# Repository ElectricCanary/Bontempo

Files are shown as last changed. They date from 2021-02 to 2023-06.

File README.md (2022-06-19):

The Bontempo is a Tap Tempo & Modulation solution for PT2399 delay

Website : https://electric-canary.com/bontempo

Support : support@electric-canary.com

Perf & PCB by storyboardist : http://effectslayouts.blogspot.com/2021/02/bomtempo.html

The Code, Schematic and PCB manufacturing files are shared under a BY-NC-SA Creative Commons License

Go here for complete license : https://creativecommons.org/licenses/by-nc-sa/4.0/legalcode

Please reach out for licencing if you want to use the code in a commercial product. 

Populated Board_Cropped - Copie

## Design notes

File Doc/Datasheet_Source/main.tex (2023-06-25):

\documentclass[a4paper, 10pt]{article}

\usepackage[default]{comfortaa}
\usepackage[utf8]{inputenc}
\usepackage[english]{babel}
\usepackage{graphicx}
\usepackage{geometry}
\usepackage{titlesec}
\usepackage{multicol}
\usepackage{lastpage}
\usepackage{fancyhdr}
\usepackage{array}
\usepackage{multirow, hhline}
\usepackage[table]{xcolor}
\usepackage[hidelinks]{hyperref}
\usepackage{textcomp}

\setlength{\columnseprule}{1pt}
\setlength{\columnsep}{1cm}

\definecolor{lightgray}{gray}{0.85}

\setlength{\arrayrulewidth}{0.35mm}
\setlength{\tabcolsep}{10pt}
\renewcommand{\arraystretch}{1.7}

\fancypagestyle{plain}{%
\fancyhf{} % clear all header and footer fields
\cfoot{\thepage /\pageref{LastPage}}
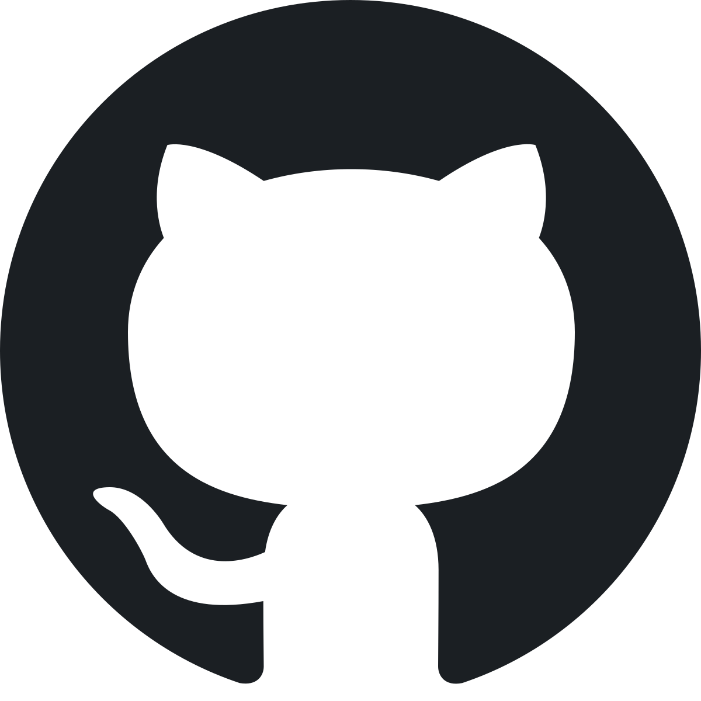
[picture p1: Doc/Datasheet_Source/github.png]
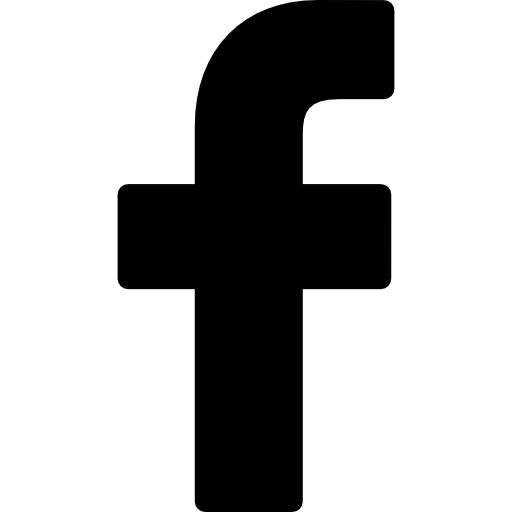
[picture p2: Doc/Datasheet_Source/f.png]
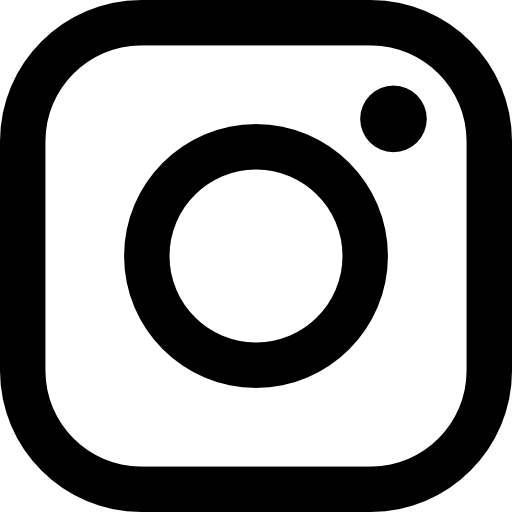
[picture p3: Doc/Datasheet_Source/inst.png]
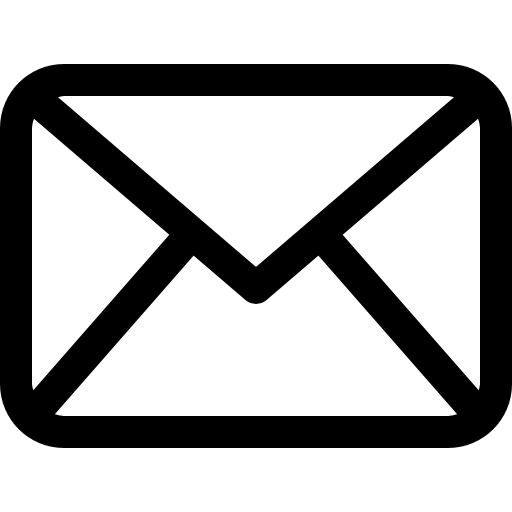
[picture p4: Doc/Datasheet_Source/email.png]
\rfoot{\href{https://github.com/ElectricCanary/Bontempo}{}\hspace{8pt}\href{https://www.facebook.com/ElectricCanary}{}\hspace{8pt}\href{https://www.instagram.com/electricanary/}{}\hspace{12pt}\href{mailto:support@electric-canary.com}{}}
\lfoot{\textcolor{black!70}{{\footnotesize\textcopyright Electric Canary - June 2020}}}
\renewcommand{\headrulewidth}{0pt}
\renewcommand{\footrulewidth}{0pt}}

\pagestyle{fancy}
\renewcommand{\headrulewidth}{0pt}
\cfoot{}
\cfoot{\thepage /\pageref{LastPage}}
\rfoot{\href{https://github.com/ElectricCanary/Bontempo}{}\hspace{8pt}\href{https://www.facebook.com/ElectricCanary}{}\hspace{8pt}\href{https://www.instagram.com/electricanary/}{}\hspace{12pt}\href{mailto:support@electric-canary.com}{}}
\lfoot{\textcolor{black!70}{{\footnotesize\textcopyright Electric Canary - June 2020}}}
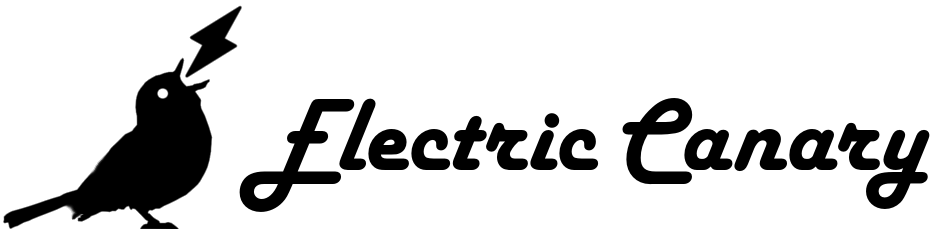
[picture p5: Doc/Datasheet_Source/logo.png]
\rhead{\href{https://electric-canary.com/bontempo}{}}
\lhead{\textbf{{\small\emph{\textcolor{black!70}{Bontempo-Datasheet}}}}}

\titleformat*{\section}{\huge\bfseries}
\titleformat*{\subsection}{\LARGE\bfseries}
\titleformat*{\subsubsection}{\Large\bfseries}

\geometry{hmargin=2.5cm,vmargin=2.5cm}
\headheight=35pt

\begin{document}\thispagestyle{plain}
\begin{center}
\begin{Huge}
\vspace*{0.5cm}
\textbf{Bontempo - Datasheet}
\rule {0.95\textwidth}{2pt}\\
\end{Huge}
\vspace{1cm}
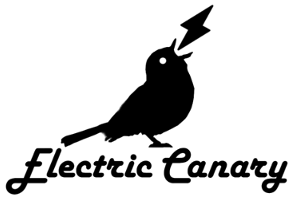
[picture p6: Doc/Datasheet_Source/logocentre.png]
\\
\end{center}
\vspace{1cm}
\begin{multicols}{2}
\section{Introduction}
\bigbreak
Bontempo is a precise Tap Tempo and Modulation integrated solution for PT2399 delay. It is suitable for new designs or modifying well-known PT2399 delays.\\

You can now unlock the full potential of your delay effect units. Explore new sonic territories with fully controllable modulation parameters and 6 modulation waveforms. \\

Get the exact tempo you need with the 6 Tempo divisions and calibration mode.\\

Keep your settings safe with the two user presets and the save tempo option. 
\vfill\null
\columnbreak

\section{Features}
\bigbreak
\begin{itemize}
\item \hyperref[sec:calib]{Calibrated }\hyperref[sec:digpot]{8-bit Digital Potentiometer Tap Tempo}
\item \hyperref[subsec:delaytime]{~40ms to ~1300ms Delay Time}
\item \hyperref[subsec:tempodiv]{6 Selectable Tempo Divisions} \\  ,  ,  ,  ,  , 
\item \hyperref[subsec:moddepthspeed]{±30ms Max. Modulation Depth}
\item \hyperref[subsec:moddepthspeed]{~0.1Hz to ~10Hz Modulation Speed}
\item \hyperref[subsec:waveformsel]{6 Selectable Modulation Waveforms}\\  ,  ,  ,  ,  , 
\item \hyperref[sec:userpresets]{2 User Presets}
\item \hyperref[sec:cleanmode]{Clean Mode (limits delay to 600ms for cleaner sound)}
\item \hyperref[sec:doubletime]{Double Time Mode}
\item \hyperref[sec:temposave]{Tempo EEPROM Save}
\item \hyperref[sec:dualpt]{Dual PT2399 Capability}
\item \hyperref[sec:pinconfig]{Compact DIP-14 Package}
\item \hyperref[sec:typappsche]{Minimal amount of External Parts}
\end{itemize}
\end{multicols}

\newpage
\headheight=35pt
\tableofcontents
\newpage

\section{Pin Configuration}
\label{sec:pinconfig}
\vfill
\begin{center}
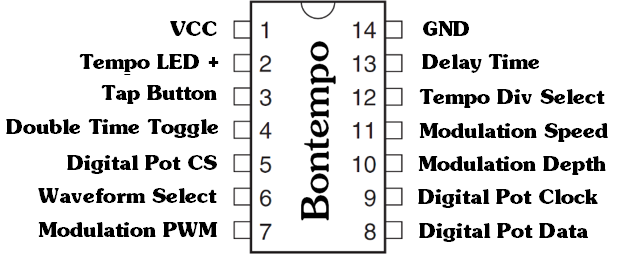
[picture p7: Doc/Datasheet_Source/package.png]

\vfill
\begin{table}[h!]
\begin{tabular}{|m{0.5cm}|m{4.5cm}|m{0.7cm}|m{7.5cm}|}
\hline
\rowcolor{lightgray} \centering {\Large\textbf{N°}} & \centering {\Large\textbf{Name}} & \centering {\Large\textbf{I/O}} & {\Large\textbf{Description}}\\
\hline
\centering 1 & \centering VCC & \centering I & Supply voltage.\\
\hline
\centering 2 & \centering Tempo LED + & \centering O & LED indicator output.\\
\hline
\centering 3 & \centering Tap Button & \centering I & Set tempo when connected  to ground.\\
\hline
\centering 4 & \centering Double Time Toggle & \centering I & Multiply tempo per 2 when connected to ground.\\
\hline
\centering 5 & \centering Digital Pot Chip Select & \centering O & Part of the SPI interface for the MCP41100 digital potentiometer.\\
\hline
\centering 6 & \centering Waveform Select & \centering I & The voltage determines the modulation waveform.\\
\hline
\centering 7 & \centering Modulation PWM & \centering O & PWM output for the MOSFET.\\
\hline
\centering 8 & \centering Digital Pot Data & \centering O & Part of the SPI interface for the MCP41100 digital potentiometer.\\
\hline
\centering 9 & \centering Digital Pot Clock & \centering O & Part of the SPI interface for the MCP41100 digital potentiometer.\\
\hline
\centering 10 & \centering Modulation Depth & \centering I & This pin's voltage determines the modulation depth between 0 and 30ms.\\
\hline
\centering 11 & \centering Modulation Speed & \centering I & This pin's voltage determines the modulation speed between 0.1 and 10Hz.\\
\hline
\centering 12 & \centering Tempo Division Select & \centering I & This pin's voltage determines the tempo division selected.\\
\hline
\centering 13 & \centering Delay Time & \centering I & This pin's voltage determines the delay time between 40 to 1300 ms if no tap sequence is active.\\
\hline
\centering 14 & \centering GND & \centering I & Ground reference voltage.\\
\hline
\end{tabular}
\caption{Pin Configuration}
\end{table}
\end{center}
\newpage

\section{Typical Application Schematic}
\label{sec:typappsche}
\bigbreak
This schematic shows how to implement the Bontempo in a simple delay project. Every options are used.
\vfill
\begin{figure} [h!]
\begin{center}
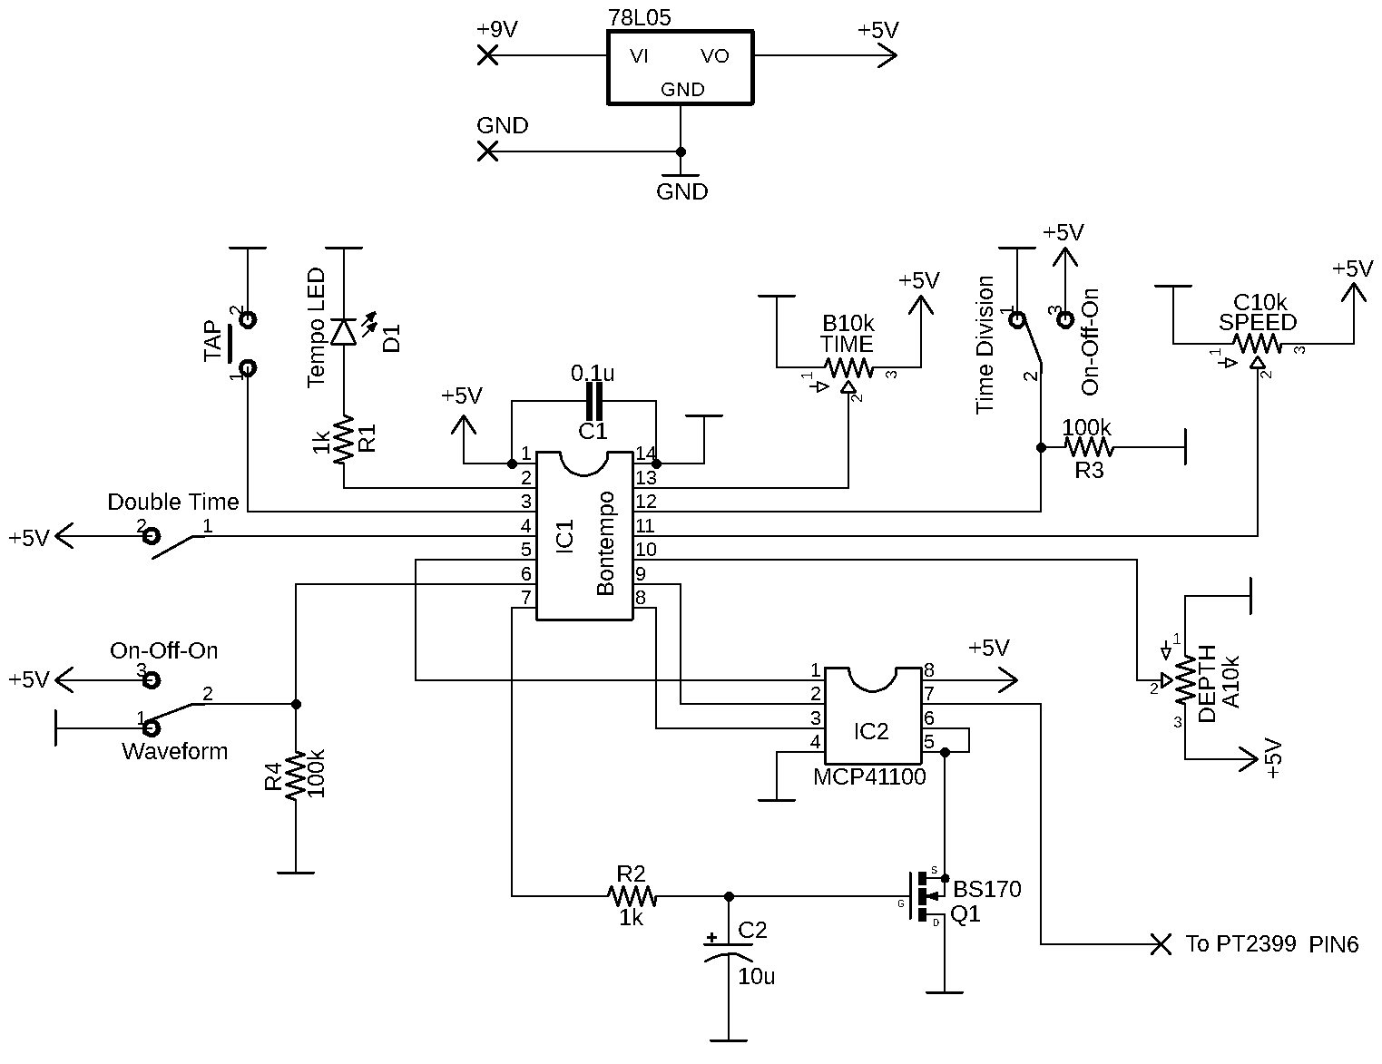
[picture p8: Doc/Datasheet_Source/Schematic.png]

\label{Schem}
\caption{Typical Application Schematic for a single PT2399}
\end{center}
\end{figure}
\vfill
\newpage
\section{Absolute Maximum Ratings}
\bigbreak
\begin{table}[h!]
\centering
\begin{tabular}{|c|c|}
\hline
Storage Temperature	& -65°C to +150°C\\
\hline
Operating Temperature & -55°C to +125°C\\
\hline
Voltage on any pin except pin 4	& -0.5V to Vcc + 0.5V\\
\hline
Voltage on Pin 4 & -0.5V to +13.0V\\
\hline
Maximum Operating Voltage & +6.0V\\
\hline
DC Current per I/O Pin & 40.0mA\\
\hline
DC Current VCC \& GND pins & 200.0mA\\
\hline
\end{tabular}
\caption{Absolute Maximum Ratings}
\end{table}
\bigbreak
\bigbreak
\section{DC Characteristics}
\bigbreak
\begin{table}[h!]
\centering
\begin{tabular}{|c|c|c|c|}
\hline
\rowcolor{lightgray}{\Large\textbf{Parameter}} & {\Large\textbf{Min}} & {\Large\textbf{Max}} & {\Large\textbf{Unit}}\\
\hline
Power Supply Voltage & 2.7 & 5.5 & V\\
\hline
Power Supply Current & 4.4 & 7 & mA\\
\hline
\end{tabular}
\caption{DC Characteristics}
\end{table}
\bigbreak
For any other DC characteristics please refer to the ATtiny84A \href{http://ww1.microchip.com/downloads/en/devicedoc/Atmel-7701_Automotive-Microcontrollers-ATtiny24-44-84_Datasheet.pdf}{\underline{datasheet}} (p.155).
\bigbreak
\bigbreak
\section{Specifications}

\begin{table}[h!]
\centering
\begin{tabular}{|c|c|c|c|}
\hline
\rowcolor{lightgray}{\Large\textbf{Parameter}} & {\Large\textbf{Min}} & {\Large\textbf{Max}} & {\Large\textbf{Unit}}\\
\hline
Delay Time & 37 & 1306 & ms\\
\hline
PWM frequency & - & 1 & kHz\\
\hline
Modulation Frequency & 0.12 & 10.17 & Hz\\
\hline
Modulation Depth & 0 & 30 & ms\\
\hline
All Potentiometer/Toggle Input & 0 & 5 & V\\
\hline
\end{tabular}
\caption{Specifications}
\end{table}

All specifications tested at VCC = 5V.

\section{Power Supply}
\bigbreak
The chip will operate with a power supply between 2.7V and 5.5V.
However a regulated 5.0V power supply is recommended. This is because the modulated tap tempo was calibrated at 5.0V and a change in Vcc will affect the PWM output voltage.
A 0.1$\mu$F capacitor should be connected between Vcc and GND and be placed as close to the pins as possible.\\

If using the same 5V regulator as the PT2399 be careful that the regulator can handle the extra load, and that the Bontempo is fed a correct voltage. \\

\section{Calibration}
\label{sec:calib}
\bigbreak
Unfortunately, not all digital potentiometers and BS170 are created equal. This is why a manual calibration phase is often necessary. Once completed it will be saved in EEPROM, but you can still re-calibrate if you're not satisfied.\\

For the very fist time it is the powered-up, the Bontempo will boot in Calibration Mode. Once the calibration finished, it will boot normally from now on.\\

The Tempo LED is blinking, to calibrate you need to make sure the delay is synced with the LED. You can finely adjust the delay time with the Time Pot. The Time Pot can add or subtract up to 200ms to the delay time. Once the delay is synced as close as possible to the LED Tempo you can press the Tap Button once.

Now the LED will blink slower and you can repeat the same operation. You'll need to do that 9 times before the calibration is over.\\

It is possible that, near the end of the calibration sequence, the delay time adjustment is not sufficient. This means you are hitting the maximum delay of the digital potentiometer. In that case just adjust the delay as close as possible.\\

The last step of calibration is a bit different. It is testing the maximum delay time. The Digital Pot is set at maximum delay and you can set the tempo of the LED with the Time Pot. The goal is still the same though, to synchronize the LED with the delay time.\\

If you want to be as precise as possible you can use an Oscilloscope or record the delay on a DAW. Each step increases the tempo by 100ms from 400 to 1200ms, the delay of the last step depends on the chip and circuit. 

To to re-calibrate the Bontempo, follow these instructions :\\
\begin{itemize}
\item Make sure the chip is powered down.
\item Press the Tap Button.
\item Power Up the Bontempo while keeping the Tap Button Pressed.
\item Keep the button pressed while the Tempo LED blinks once.
\item After the LED blinks twice you have 2s to release the Tap Button.
\item The LED will blink twice quickly and you are now in Calibration Mode.\\
\end{itemize}

\newpage
\section{Controls}
\subsection{Tap Tempo Button}
\bigbreak
This input is only compatible with a momentary switch.
The debounce is handled by software so no extra external components have to be used. Debounce time is 500$\mu$s.\\

The program starts counting milliseconds after the first press. The delay time tapped is in effect right after the second press of the tap button. After the second press of the tap button, every following tap in the sequence is averaged in order to reach easily the desired tempo. 

If the button is not pressed again after a certain time ,the timer is reset and the tap sequence is ended. When a tap sequence has started, it will take 2 cycles to be finished (the LED will start blinking). If the tap tempo button is pressed only once, the tap sequence will be aborted after the reset time passed (see table below).\\

\begin{table}[h!]
\centering
\begin{tabular}{|c|c|c|}
\hline
\rowcolor{lightgray}{\Large\textbf{Time Division Selected}} & {\Large\textbf{Normal}} & {\Large\textbf{Clean Mode}}\\
\hline
 & 2.1s & 1.4s\\
\hline
 & 2.5s & 1.6s\\
\hline
 & 3.4s & 2s\\
\hline
 & 4.7s & 2.6s\\
\hline
 & 6s & 3.2s\\
\hline
 & 8.6s & 4.4s\\
\hline
\end{tabular}
\caption{Tap Sequence Reset Time}
\end{table}

The reset time follows this equation: $\frac{Max Delay}{Tempo Div Mult} + 800 = Reset Time (ms)$\\

Max Delay is around 1300ms in normal mode and 600ms in clean mode. Tempo Div Mult is the multiplier of the current time division (1, 0.75, 0.5, 0.33, 0.25, 0.17).\\

When the tap tempo is active, the tempo LED will blink with the rhythm you tapped, regardless of the selected tempo division.\\

\subsection{Delay Time}
\label{subsec:delaytime}
\bigbreak
This input is to voltage control the delay time. This input will control the delay time until you activate the tap tempo. While the delay time is controlled by this input, the Tempo LED and Scale LED will stay on.\\

To take back control from the Tap Tempo, you just need to modify this input's voltage by 5\%.Typically, you would use a Potentiometer for the delay time control. The recommended potentiometer value is 10k$\Omega$ or above, to avoid having too much current going through the pin.\\

You can add a 0.1$\mu$F capacitor between the input and ground for smoother time changes.\\

\subsection{Tempo Division Select}
\label{subsec:tempodiv}
\bigbreak
Six different tempo division are accessible with this input. To access every time division a SPDT On-Off-On toggle switch is required.\\

The first three time divisions are fourth, dotted eighth and eighth. The last three time divisions are accessed by first pressing the tap button and then changing the toggle position while the tap button is pressed. The press will not count as a press for the tap tempo. The three last time divisions are triplet, sixteenth and sextuplet.\\

The time divisions are selected by changing the Tempo Div Select Pin's voltage (Pin 12).\\

\begin{table}[h!]
\centering
\begin{tabular}{|c|l|l|}
\hline
\rowcolor{lightgray} & \multicolumn{2}{c|}{{\Large\textbf{Tempo Division}}}\\
\hhline{|>{\arrayrulecolor{lightgray}}->{\arrayrulecolor{black}}|--|}
\rowcolor{lightgray}\multirow{-2}{5cm}{\centering{\Large\textbf{Pin 12 Voltage}}} & {\centering\large\textbf{Not Pressed}} & {\centering\large\textbf{Button Pressed}}\\
\hline
GND - 0.39V & Fourth \hfill  & Triplet \hfill \\
\hline
0.4V - 4.4V & Dotted-Eighth \hfill & Sixteeth \hfill \\
\hline
4.5V - 5V & Eighth \hfill  & Sextuplet \hfill \\
\hline
\end{tabular}
\caption{Modulation Waveform Selection}
\end{table}

If the time division is changed while the Tap Tempo is active, the delay time will be changed accordingly instantly.\\

You can access the middle time division by putting a resistor between pin 12 and ground. Any value between 5k$\Omega$ and 140k$\Omega$ would potentially work, but a 100k$\Omega$ resistor is recommended in order not to draw too much current.\\

\subsection{Modulation Depth \& Speed}
\label{subsec:moddepthspeed}
\bigbreak
Same recommendations than the Delay Time (10k$\Omega$ or more, 0.1$\mu$F capacitor …).\\

Modulation speed goes from 0.12Hz to 10.17Hz. Modulation depth maximum is 30ms.\\

\subsection{Modulation Waveform Select}
\label{subsec:waveformsel}
\bigbreak
Six different modulation waveforms are accessible with this input. To access every waveform a SPDT On-Off-On toggle switch is required. 
The first three waveforms are sine, square and triangle. The last three waveforms are accessed by first pressing the tap button and then changing the toggle position while the tap button is pressed. The press will not count as a press for the tap tempo. The last three modulation waveforms are Ramp-up, Ramp-Down and Random.\\

The modulation waveforms are selected by changing the Modulation Waveform Select Pin's voltage (Pin6).\\
\newpage
\begin{table}[h!]
\centering
\begin{tabular}{|c|l|l|}
\hline
\rowcolor{lightgray} & \multicolumn{2}{c|}{{\Large\textbf{Waveform}}}\\
\hhline{|>{\arrayrulecolor{lightgray}}->{\arrayrulecolor{black}}|--|}
\rowcolor{lightgray}\multirow{-2}{5cm}{\centering{\Large\textbf{Pin 6 Voltage}}} & {\centering\large\textbf{Not Pressed}} & {\centering\large\textbf{Button Pressed}}\\
\hline
GND - 0.39V & Sine \hfill  & Ramp-Up \hfill \\
\hline
0.4V - 4.4V & Square \hfill & Ramp-Down \hfill \\
\hline
4.5V - 5V & Triangle \hfill  & Random \hfill \\
\hline
\end{tabular}
\caption{Modulation Waveform Selection}
\end{table}
The waveforms can sound a bit asymmetrical at high modulation depth, this is due to the MOSFET’s non-linearity. \\

Like for the Time Division Toggle, a 100k$\Omega$ resistor is recommended to access the middle waveform.\\

\subsection{Double Time}
\label{sec:doubletime}
\bigbreak
The double time divide the time division multiplier per two. This results in tempo that's two time faster. This effect is not affected by preset recall. Double Time has no effect on the Delay Time when controlled by the Delay Time input.
This effect can be used dynamically or just set as wanted.\\

When the Double Time Pin (Pin 4) is connected to Vcc, the double time mode is active. If the Double Time Pin is connected to Ground, the double time mode is disabled.\\ 
\newpage
\section{User Presets}
\label{sec:userpresets}
\bigbreak
You can easily save and recall two user presets on the Bontempo. These presets are saved on the Bontempo's EEPROM so that they can survive the power cycles.\\

To recall preset 1 you must:\\
\begin{itemize}
\item Push the Tap Button and keep it pressed for 3s.
\item After the LED blinks once, release the Tap Button.
\item The LED will blink once quickly and preset 1 is recalled.\\
\end{itemize}

To recall preset 2 you must:\\
\begin{itemize}
\item Push the Tap Button and keep it pressed for 3s.
\item Keep it pressed while the LED blinks once.
\item After the LED blinks twice, release the Tap Button.
\item The LED will blink twice again quickly and preset 2 is recalled.\\
\end{itemize}

To save preset 1 you must:\\
\begin{itemize}
\item Push the Tap Button and keep it pressed for 3s.
\item Keep it pressed while the LED blinks once.
\item Keep it pressed while the LED blinks twice.
\item After the LED "reverse-blinks" once, release the  Tap Button.
\item The LED will "reverse-blink" once again quickly and preset 1 is now saved.\\
\end{itemize}

To save preset 2 you must:\\
\begin{itemize}
\item Push the Tap Button and keep it pressed for 3s.
\item Keep it pressed while the LED blinks once.
\item Keep it pressed while the LED blinks twice.
\item Keep it pressed while the LED "reverse-blinks" once.
\item After the LED "reverse-blinks" twice, release the  Tap Button.
\item The LED will "reverse-blink" twice again quickly and preset 2 is now saved.\\
\end{itemize}

Keep in mind that, unfortunately, the Feedback setting in delay circuits cannot be saved since it's not controlled by the Bontempo.

Furthermore, the double time toggle cannot be saved in presets but will still affect the tempo even when a preset is recalled. This applies for the clean mode too.\\

The tempo (tapped or set with a potentiometer), the tempo division, the modulation speed, modulation depth and modulation waveform can be saved and recalled at will.

The recalled tempo will not take the clean mode into account.\\

Once you recall a preset, any parameters can be changed without affecting the other preset's parameters.\\

\section{Tempo Save}
\label{sec:temposave}
\bigbreak
When you tap a tempo it is saved on the Bontempo's EEPROM. This means that if you power down the Bontempo while a tap sequence is active, the Bontempo will resume this sequence when powered up. This is true even if some parameters are moved when the Bontempo is powered down.\\
\section{Clean Mode}
\label{sec:cleanmode}
\bigbreak
The clean mode limits the maximum tempo to 600ms. This will produce a less distorted delay. This will emulate a 50k$\Omega$ time potentiometer, like some PT2399 delay.
\bigbreak
To activate the Clean Mode, you need to:
\begin{itemize}
\item Make sure the chip is powered down.
\item Press the Tap Button.
\item Power Up the Bontempo while keeping the Tap Button Pressed.
\item Keep the button pressed until the Tempo LED blinks once.
\item You now have 2s to release the button, the LED will blink   once again quickly.
\item You are now in Clean Mode.
\end{itemize}
\bigbreak
This status is written in the chip's EEPROM. This mean the Bontempo will boot in clean mode every time.
To deactivate Clean Mode, just repeat the procedure above. The chip will now boot in normal mode every time.\\

\section{Deactivating Modulation}
\bigbreak
If you don’t wish to use the modulation features, just connect Waveform Select Pin (Pin 6), Modulation Depth (Pin 10) and Modulation Speed (Pin 11) to ground.\\

Do not disconnect the BS170 MOSFET !\\

The BS170 is taken into account during the calibration. Discarding the MOSFET will result in extremely imprecise tap sequences.\\
\newpage
\section{Digital Potentiometer SPI Interface}
\label{sec:digpot}
\bigbreak
The only digital potentiometer guaranteed to work are the MCP41100 and MCP42100. They are 8bit 100kΩ SPI controlled digital potentiometers. The SPI interface requires 3 pins (Clock, Data and Chip Select). Since the potentiometer is 8bit, it has 256 different wiper positions. This limits the tempo precision to approximately 5ms. For more information about the digital potentiometers see the \href{http://ww1.microchip.com/downloads/en/DeviceDoc/11195c.pdf}{\underline{datasheet}}.\\

Please be careful with the connection between the digital potentiometer and the PT2399, as the PT2399 is sensible to noise and this could throw off the calibration. Keep the connection short and direct.\\

\section{PWM Output}
\bigbreak
Modulation and precision compensation on the Bontempo is achieved by outputting a voltage to a BS170 MOSFET in series with the digital potentiometer. The PWM frequency is 1kHz, since this frequency is the audible spectrum, we need to filter it. If a filter is not used it will result in some ring modulation in the modulated delay signal.\\

The chip is calibrated with a first order filter composed of a 1k$\Omega$ resistor and a 10$\mu$F capacitor. The 1kHz is reduced by 36dB by this filter, which is sufficient to the ring modulation inaudible.\\

\section{Dual PT2399 Operation}
\label{sec:dualpt}
\bigbreak
If you wish to use the Bontempo in a dual PT2399 design, the Double Time Toggle Pin will become a "Half-Time Toggle Pin". If you don't wish to use this feature dynamically, just connect Pin4 to Vcc. \\

%\begin{figure}[h!]
%\centering
%\includegraphics[scale=0.7]{DualSchematic}
%\caption{Typical Application Schematic for Dual PT2399 Operation}
%\end{figure}

\section{Tempo LED}
\bigbreak
When the delay time is controlled by the Delay Time input the LED will stay on.\\

When tapping a tap sequence, the LED will blink exactly when you press the tap button, beginning with the second press.\\

When the Tap Tempo is active, the tempo LED will blink in sync with the tempo you tapped regardless of the tempo division selected. During the blinking phase, the LED stays on for 8ms.\\

\end{document}

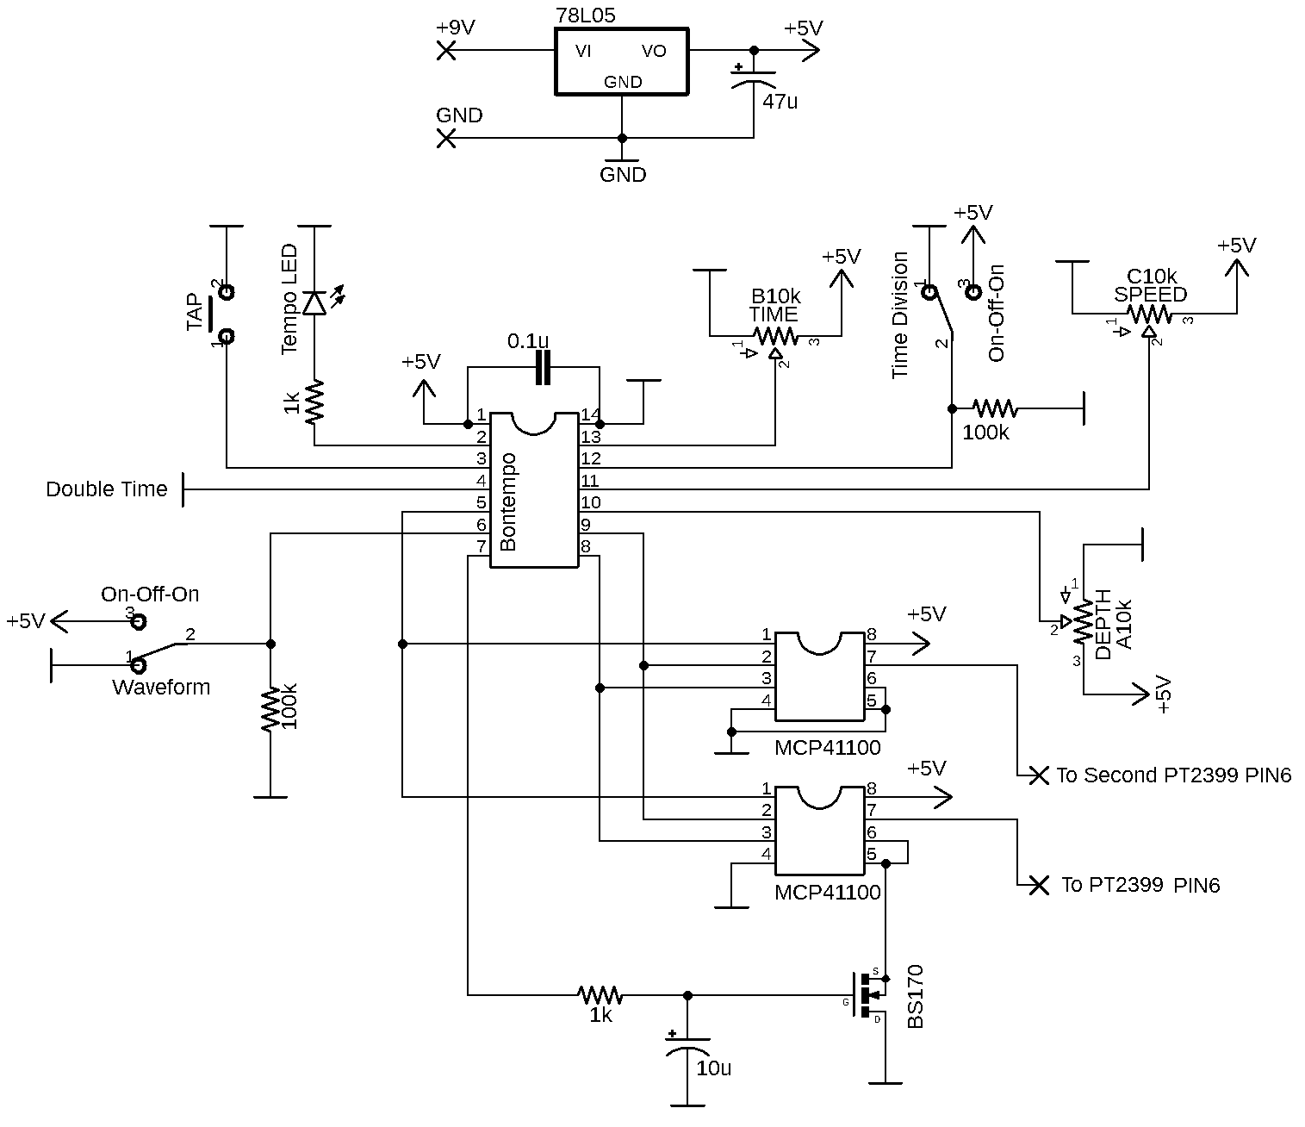
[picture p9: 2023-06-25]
Doc/Datasheet_Source/DualSchematic.png

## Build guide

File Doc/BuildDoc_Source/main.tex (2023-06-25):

\documentclass[a4paper, 10pt]{article}

\usepackage[default]{comfortaa}
\usepackage[utf8]{inputenc}
\usepackage[english]{babel}
\usepackage{graphicx}
\usepackage{geometry}
\usepackage{titlesec}
\usepackage{multicol}
\usepackage{lastpage}
\usepackage{fancyhdr}
\usepackage{array}
\usepackage{multirow, hhline}
\usepackage[table]{xcolor}
\usepackage[hidelinks]{hyperref}
\usepackage{textcomp}

\setlength{\columnsep}{1cm}

\definecolor{lightgray}{gray}{0.85}

\setlength{\arrayrulewidth}{0.35mm}
\setlength{\tabcolsep}{10pt}
\renewcommand{\arraystretch}{2}

\fancypagestyle{plain}{%
\fancyhf{} % clear all header and footer fields
\cfoot{\thepage /\pageref{LastPage}}
\rfoot{\href{https://github.com/ElectricCanary/Bontempo}{}\hspace{8pt}\href{https://www.facebook.com/ElectricCanary}{}\hspace{8pt}\href{https://www.instagram.com/electricanary/}{}\hspace{12pt}\href{mailto:support@electric-canary.com}{}}
\lfoot{\textcolor{black!70}{{\footnotesize\textcopyright Electric Canary - June 2020}}}
\renewcommand{\headrulewidth}{0pt}
\renewcommand{\footrulewidth}{0pt}}

\pagestyle{fancy}
\renewcommand{\headrulewidth}{0pt}
\cfoot{}
\cfoot{\thepage /\pageref{LastPage}}
\rfoot{\href{https://github.com/ElectricCanary/Bontempo}{}\hspace{8pt}\href{https://www.facebook.com/ElectricCanary}{}\hspace{8pt}\href{https://www.instagram.com/electricanary/}{}\hspace{12pt}\href{mailto:support@electric-canary.com}{}}
\lfoot{\textcolor{black!70}{{\footnotesize\textcopyright Electric Canary - June 2020}}}
\rhead{\href{https://electric-canary.com/bontempo}{}}
\lhead{\textbf{{\small\emph{\textcolor{black!70}{Bontempo - Build Documentation}}}}}

\titleformat*{\section}{\huge\bfseries}
\titleformat*{\subsection}{\LARGE\bfseries}
\titleformat*{\subsubsection}{\Large\bfseries}

\geometry{hmargin=2.5cm,vmargin=2.5cm}
\headheight=35pt

\begin{document}\thispagestyle{plain}
\begin{center}
\begin{Huge}
\vspace*{0.5cm}
\textbf{Bontempo - Build Documentation}
\rule {0.95\textwidth}{2pt}\\
\end{Huge}
\vspace{1cm}
\\
\end{center}
\vspace{1cm}
Bontempo is a Tap Tempo \& Modulation solution for PT2399 delay. You do need a PT2399 delay circuit to use with the Bontempo PCB. This is a build guide for the Bontempo PCB. For any information about operating the Bontempo please refer to the \href{https://electric-canary.com/assets/bontempo---datasheet.pdf}{\underline{datasheet}}. \\

\vfill
\begin{center}
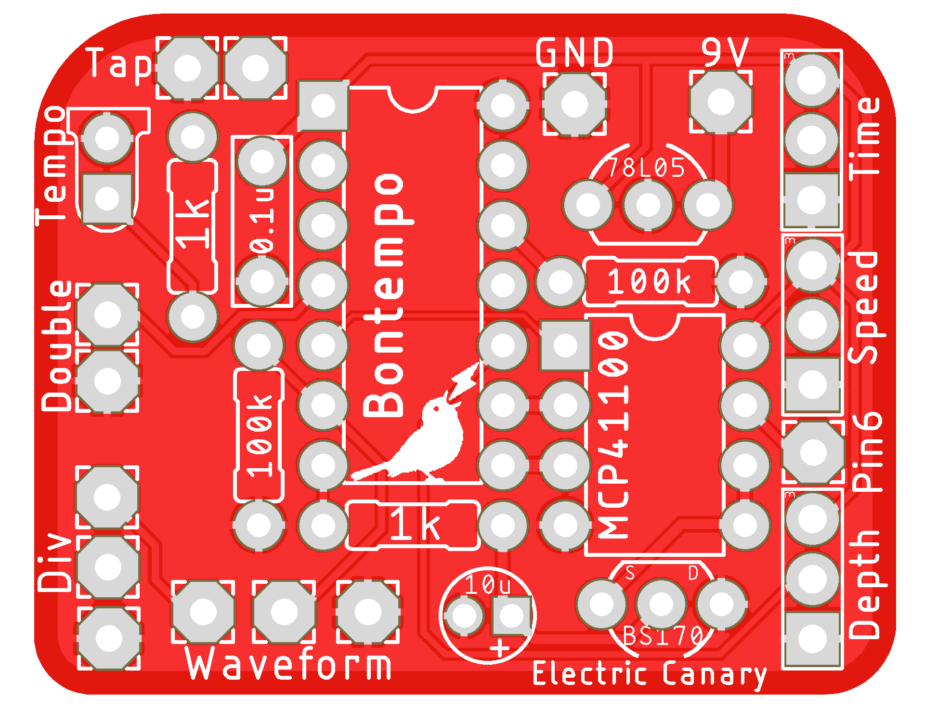
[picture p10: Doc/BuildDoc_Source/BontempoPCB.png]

\end{center}
\vfill
\newpage
\section{Schematic}

\section{Bill of Materials}
\begin{multicols}{2}
{\rowcolors{1}{}{lightgray!50}
\begin{tabular}{|c|c|}
\hline
\rowcolor{gray}{\LARGE\textcolor{white}{\textbf{Name}}} &  {\LARGE\textcolor{white}{\textbf{Value}}}\\
\hline
R1 & 1k$\Omega$ (more for dimmer LED)\\
\hline
R2 & 1k$\Omega$ \\
\hline
R3 & 100k$\Omega$ \\
\hline
R4 & 100k$\Omega$ \\
\hline
C1 & 100nF \\
\hline
C2 & 10$\mu$F \\
\hline
 &  \\
\hline
D1 & Tempo LED \\
\hline
Q1 & BS170 \\
\hline
\end{tabular}}
\columnbreak
\begin{flushright}
{\rowcolors{1}{}{lightgray!50}
\begin{tabular}{|c|c|}
\hline
\rowcolor{gray}{\LARGE\textcolor{white}{\textbf{Name}}} &  {\LARGE\textcolor{white}{\textbf{Value}}}\\
\hline
IC1 & Bontempo\\
\hline
IC2 & MCP41100 \\
\hline
Time & B10k\\
\hline
Speed & C10k \\
\hline
Depth & A10k \\
\hline
Tap & Momentary SPST \\
\hline
Time Division & SPDT On-Off-On \\
\hline
Waveform & SPDT On-Off-On \\
\hline
Double Time & SPST \\
\hline
\end{tabular}}
\end{flushright}
\end{multicols}
\newpage
\section{Wiring Diagram}
\bigbreak
\begin{center}
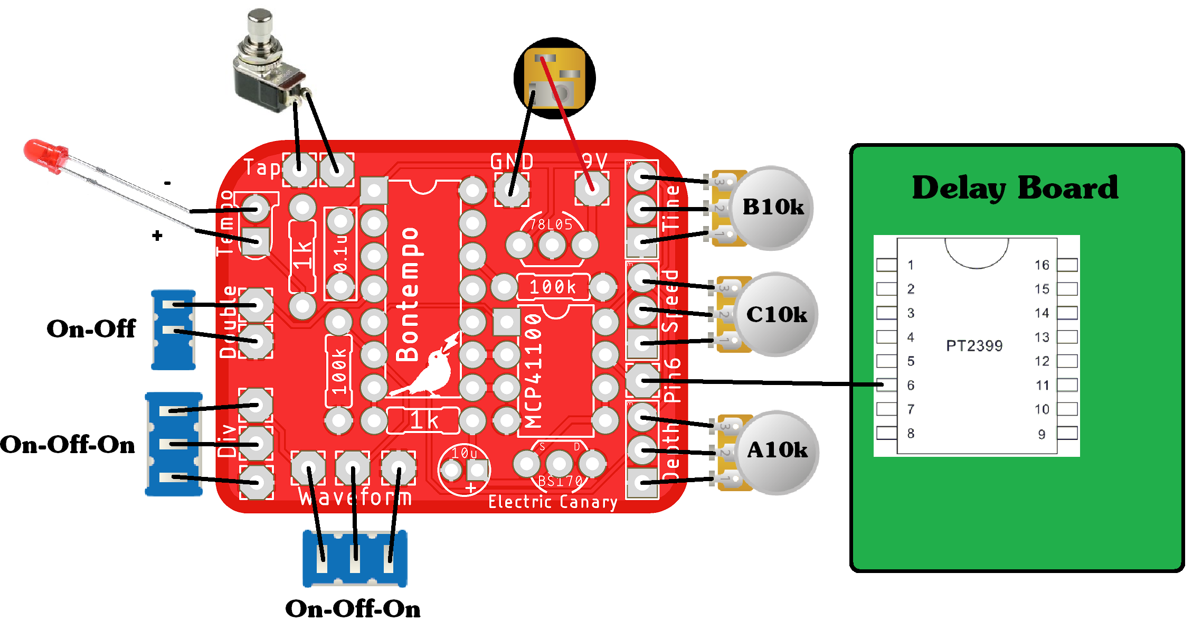
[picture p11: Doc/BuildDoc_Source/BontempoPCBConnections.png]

\end{center}
\section{Build Notes}
\begin{itemize}
\item Don't forget to calibrate the Tap Tempo once you're finished ! (\href{https://electric-canary.com/assets/bontempo---datasheet.pdf}{\underline{Datasheet}} Section 9.)
\item Make sure to omit the Delay Time Pot and any resistors connected to the PT2399 Pin6 in the delay circuit. 
\item Make sure the connection between the Bontempo Board and the Delay Board is as short and secured as possible. 
\item If you don't wish to use the Double Time switch dynamically just omit the switch.
\item Theoretically any value between 5k$\Omega$ and 140k$\Omega$ could work for R3 and R4.
\item Similarly, higher values for the pots could be used. Lower values are not recommended.
\item If the LED is too bright you can augment R1 value. 4.7k$\Omega$ can be nicer for super-bright LEDs.
\item Square pads represent pin 1 of pots, + for LED, + for polarized capacitors and pin 1 for ICs.
\item Mind the way you orient switches.
\end{itemize}
\end{document}

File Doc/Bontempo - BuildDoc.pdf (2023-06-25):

# Bontempo - Build Documentation

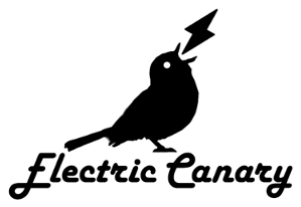
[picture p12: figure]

Bontempo is a Tap Tempo & Modulation solution for PT2399 delay. You do need a PT2399 delay circuit to use with the Bontempo PCB. This is a build guide for the Bontempo PCB. For any information about operating the Bontempo please refer to the datasheet. (https://electric-canary.com/assets/bontempo---datasheet.pdf)

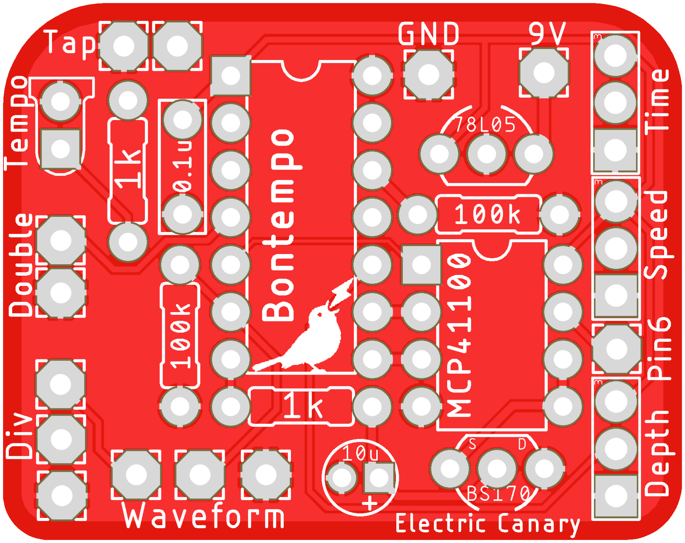
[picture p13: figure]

©Electric Canary - June 2020 | 1/3

Bontempo - Build Documentation

# 1 Schematic


# 2 Bill of Materials

Name | Value
R1 | 1kΩ (more for dimmer LED)
R2 | 1kΩ
R3 | 100kΩ
R4 | 100kΩ
C1 | 100nF
C2 | 10µF
D1 | Tempo LED
Q1 | BS170
Name | Value
IC1 | Bontempo
IC2 | MCP41100
Time | B10k
Speed | C10k
Depth | A10k
Tap | Momentary SPST
Time Division | SPDT On-O-On
Waveform | SPDT On-O-On
Double Time | SPST

Bontempo - Build Documentation

# 3 Wiring Diagram

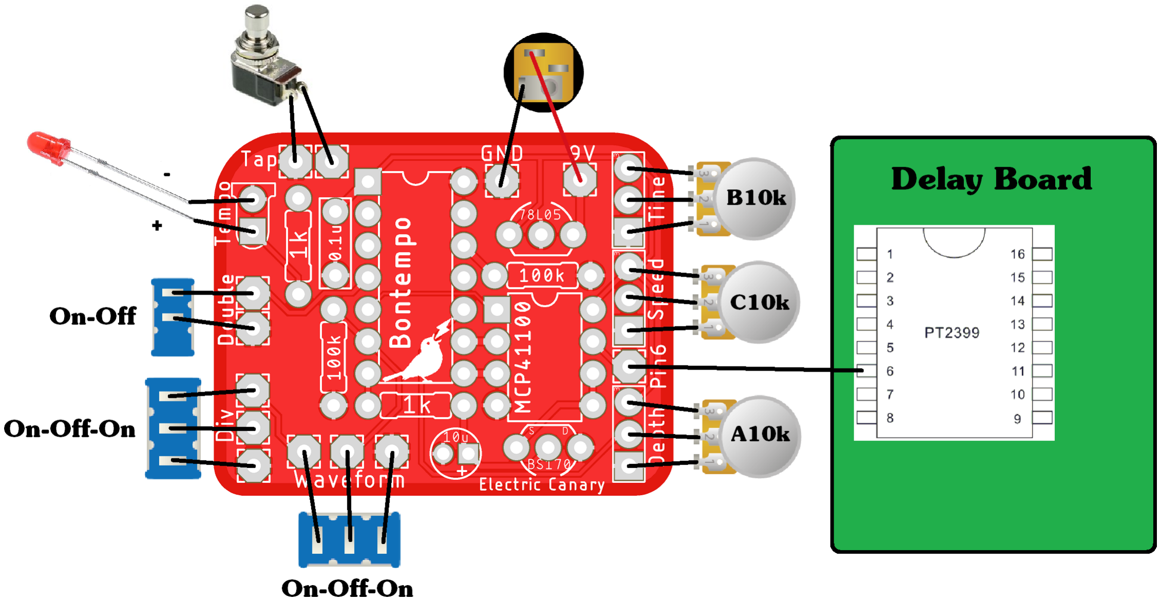
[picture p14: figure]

# 4 Build Notes

- Don’t forget to calibrate the Tap Tempo once you’re finished ! (Datasheet (https://electric-canary.com/assets/bontempo---datasheet.pdf) Section 9.)
- Make sure to omit the Delay Time Pot and any resistors connected to the PT2399 Pin6 in the delay circuit.
- Make sure the connection between the Bontempo Board and the Delay Board is as short and secured as possible.
- If you don’t wish to use the Double Time switch dynamically just omit the switch.
- Theoretically any value between 5kΩ and 140kΩ could work for R3 and R4.
- Similarly, higher values for the pots could be used. Lower values are not recommended.
- If the LED is too bright you can augment R1 value. 4.7kΩ can be nicer for super-bright LEDs.
- Square pads represent pin 1 of pots, + for LED, + for polarized capacitors and pin 1 for ICs.
- Mind the way you orient switches.

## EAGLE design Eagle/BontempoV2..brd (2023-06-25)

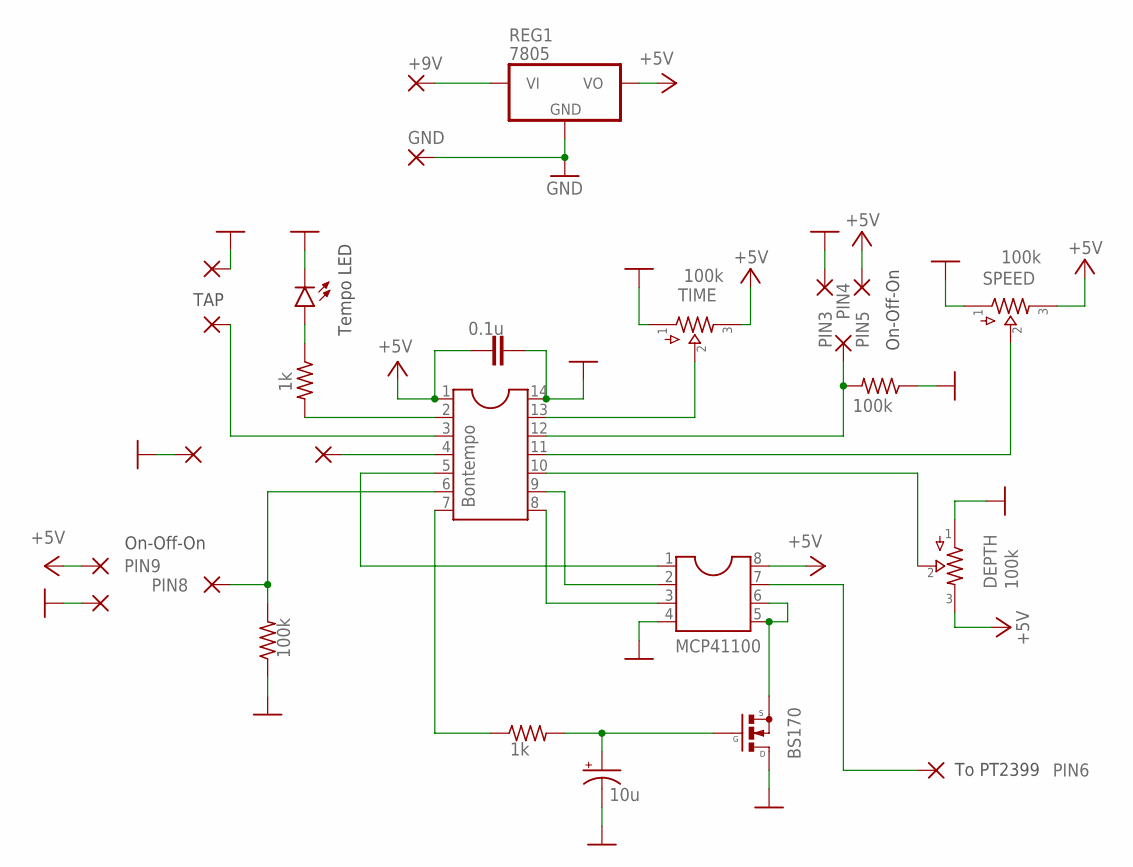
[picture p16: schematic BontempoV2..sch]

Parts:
+9V: 2,54/1,1
C1: 10u; 050_020
C2: 0.1u; BOX_SMALL
D1: LED3MM
DEPTH: 100k; PADS_SMALL
GND: 2,54/1,1
IC1: Bontempo; DIL14
IC2: MCP41100; DIL08
PIN1, PIN2, PIN3, PIN4, PIN5, PIN6, PIN7, PIN8, PIN9, PIN11, PIN12: 2,54/1,1
Q1: BS170; SOT54ES
R1, R3: 1k; R0207/3
R4, R5: 100k; R0207/3
REG1: 7805; TO92-
SPEED: 100k; PADS_SMALL
TIME: 100k; PADS_SMALL

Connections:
+5V: C2.1, DEPTH.3, IC1.1, IC2.8, PIN5.1, PIN9.1, REG1.3 (VO), SPEED.3, TIME.3
GND: C1.-, C2.2, D1.K (C), DEPTH.1, GND.1, IC1.14, IC2.4, PIN2.1, PIN3.1, PIN7.1, PIN11.1, Q1.D, R4.1, R5.1, REG1.2 (GND), SPEED.1, TIME.1
unnamed: IC1.2, R1.2
unnamed: IC2.5, IC2.6, Q1.S
unnamed: IC1.9, IC2.2
unnamed: IC1.8, IC2.3
unnamed: D1.A, R1.1
unnamed: IC1.4, PIN12.1
unnamed: IC1.3, PIN1.1
unnamed: C1.+, Q1.G, R3.2
unnamed: IC1.7, R3.1
unnamed: IC1.5, IC2.1
unnamed: IC1.6, PIN8.1, R4.2
unnamed: IC1.13, TIME.2
unnamed: IC1.11, SPEED.2
unnamed: IC1.12, PIN4.1, R5.2
unnamed: DEPTH.2, IC1.10
unnamed: +9V.1, REG1.1 (VI)
unnamed: IC2.7, PIN6.1

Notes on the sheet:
On-Off-On
To PT2399
Tempo LED
TAP

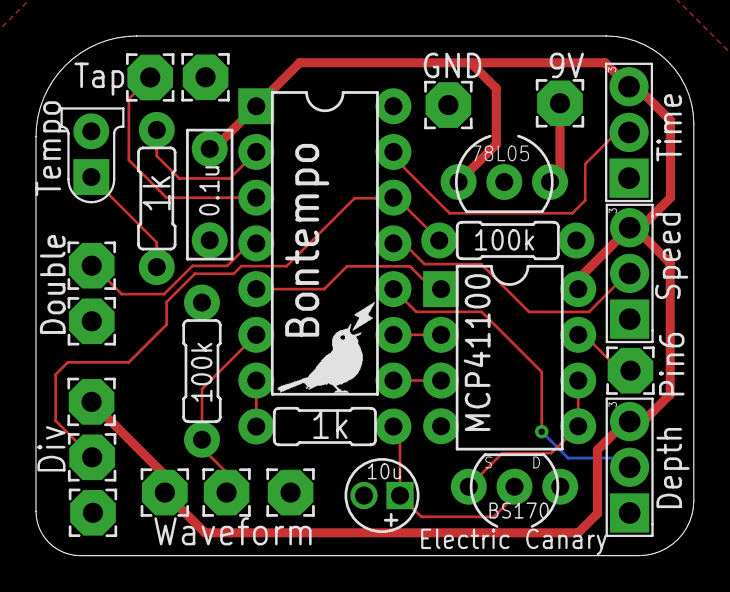
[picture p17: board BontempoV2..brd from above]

Board: 2 copper layers, 36.5 x 28.9 mm, 27 parts (0 on the bottom side), 19 nets.

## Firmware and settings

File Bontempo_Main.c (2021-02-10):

/*
 * Bontempo
 * June 2020
 * Author : Antoine Ricoux for Electric Canary
 https://electric-canary.com/bontempo
 support@electric-canary.com
 
 
 This is a tap tempo with modulation for PT2399-based delay
 This code is created for the ATtiny84A and digital potentiometer MCP41100 (or MCP42100)
 
 Pin configuration :
 
 1: VCC
 2: LED +
 3: Tap Momentary Button
 4: Double Time
 5: SPI Chip Select
 6: Waveform Toggle (On-Off-On)
 7: Mod PWM Out
 8: SPI Data Out
 9: SPI Clock Out
 10: Mod Depth Potentiometer
 11: Mod Speed Potentiometer 
 12: Time Div Toggle (On-Off-On)
 13: Time Potentiometer
 14: GND
 
 Recommended fuses : 
 Reset Pin Enabled, Double Time Disabled: Low Fuse = 0xd2	High Fuse = 0xdc
 (!)Reset Pin Disabled(!), Double Time Enabled: Low Fuse = 0xd2	High Fuse = 0x5c
 Don't forget to use Release mode in AtmelStudio.
 
 Thanks to Florian Dupeyron for helping me debug some stuff
 
 This code is shared shared under a BY-NC-SA Creative Commons License
 Go here for complete license : https://creativecommons.org/licenses/by-nc-sa/4.0/legalcode
 
 */ 

#include <avr/io.h>
#define F_CPU 8000000UL
#include <util/delay.h>
#include <avr/eeprom.h>
#include <math.h>
#include <avr/interrupt.h>
#include <avr/pgmspace.h>

#define LEDPORT PORTB		//Defining every pin, DDR & port used
#define LEDPIN	PINB0
#define LEDDDR	DDRB
#define DOUBLEPIN PINB3
#define DOUBLEPORT PORTB
#define DOUBLESFR PINB
#define DOUBLEBV 3
#define BUTTONPIN PINB1
#define BUTTONPORT PORTB
#define BUTTONSFR PINB
#define BUTTONBV 1
#define SPIDDR DDRA
#define SPIPORT PORTA
#define CSPORT PORTB
#define CSDDR DDRB
#define CSPIN PINB2
#define CLKPIN PINA4
#define DATAPIN PINA5
#define PWMPIN PINA6
#define PWMBV 6
#define PWMDDR DDRA
#define DIVPORT PORTA
#define DIVPIN PINA1
#define MODPORT PORTA
#define MODSFR PINA
#define WAVEBV 7
#define WAVEPIN PINA7
#define SPEEDPIN PINA2
#define SPEEDBV 2
#define DEPTHPIN PINA3
#define DEPTHBV 3
#define N_ARRAY 256
#define DEBOUNCE_TIME 800	//Tap button debounce time in microseconds
#define RAND_MAX 0x7fff
#define PI 3.14159265

volatile unsigned long timevalue;
volatile uint8_t divtogglevalue;
volatile uint16_t msturns = 0;
volatile uint16_t ledturns = 0;
volatile uint8_t inc = 0;
volatile uint8_t speedvalue;
volatile unsigned long depthvalue;
volatile uint8_t wavevalue;
volatile unsigned long currentinc = 500;
volatile uint16_t pwm;
volatile uint16_t speed;

PROGMEM const uint16_t tempo[] = {	//wiper position to tempo conversion chart
			51,52,54,59,65,71,77,83,89,94,99,105,110,115,120,125,131,136,141,146,
			152,157,162,168,173,179,185,190,196,201,206,211,217,222,227,232,237,242,247,252,
			257,262,267,272,277,282,287,292,298,302,307,312,317,322,327,332,338,343,348,353,
			359,364,369,374,379,384,389,394,399,405,410,415,420,425,430,435,439,444,449,454,
			459,464,469,474,479,484,488,493,498,503,507,512,517,522,527,532,537,542,547,551,
			556,561,566,571,576,581,586,591,596,601,606,611,615,620,625,630,635,640,645,650,
			655,660,664,669,674,679,684,688,693,698,703,708,713,718,722,727,732,737,741,746,
			750,755,760,765,770,775,779,784,789,794,798,803,808,812,817,822,827,831,836,841,
			846,850,855,860,865,869,874,879,884,888,893,898,903,908,912,917,922,926,931,936,
			941,945,950,955,960,965,969,974,979,983,988,993,997,1002,1007,1012,1017,1021,1026,1031,
			1036,1040,1045,1049,1054,1058,1063,1068,1073,1078,1082,1087,1092,1097,1101,1106,1110,1115,1120,1124,
			1129,1133,1138,1142,1147,1152,1157,1162,1166,1171,1175,1180,1185,1189,1194,1199,1203,1208,1212,1217,
			1222,1226,1231,1236,1241,1245,1250,1254,1259,1264,1268,1273,1277,1282,1287,1291};

uint8_t debounce(void)					//tells with certainty if button is pressed
{
	if (bit_is_clear(BUTTONSFR,BUTTONBV))		//if button pressed
	{
		_delay_us(DEBOUNCE_TIME);				//wait debounce time
		if (bit_is_clear(BUTTONSFR,BUTTONBV))	//if still pressed return 1
		{
			return(1);
		}
		else									//if not return 0
		{
			return(0);
		}
	}
	else
	{
		return(0);
	}
}

int getClosest(int, int, int, int, int); 
  
// Returns element closest to target in arr[] and return wiper position
int findClosest(int target) 
{ 
    // Corner cases 
    if (target <= pgm_read_word_near(tempo + 0)) 
        return 0; 
    if (target >= pgm_read_word_near(tempo + (N_ARRAY-1))) 
        return N_ARRAY - 1; 
  
    // Doing binary search 
    int i = 0, j = N_ARRAY, mid = 0; 
    while (i < j) { 
        mid = (i + j) / 2; 
  
        if (pgm_read_word_near(tempo + mid) == target) 
            return mid; 
  
        /* If target is less than array element, 
            then search in left */
        if (target < pgm_read_word_near(tempo + mid)) { 
  
            // If target is greater than previous 
            // to mid, return closest of two 
            if (mid > 0 && target > pgm_read_word_near(tempo + (mid - 1))) 
                return getClosest(pgm_read_word_near(tempo + (mid - 1)), 
                                  pgm_read_word_near(tempo + mid), target, mid-1, mid); 
  
            /* Repeat for left half */
            j = mid; 
        } 
  
        // If target is greater than mid 
        else { 
            if (mid < N_ARRAY - 1 && target < pgm_read_word_near(tempo + (mid + 1))) 
                return getClosest(pgm_read_word_near(tempo + mid), 
                                  pgm_read_word_near(tempo + (mid + 1)), target, mid, mid+1); 
            // update i 
            i = mid + 1;  
        } 
    } 
  
    // Only single element left after search 
    return mid; 
} 
  
// Method to compare which one is the more close. 
// We find the closest by taking the difference 
// between the target and both values. It assumes 
// that val2 is greater than val1 and target lies 
// between these two. 
int getClosest(int val1, int val2, 
               int target, int n1, int n2) 
{ 
    if (target - val1 >= val2 - target) 
        return n2; 
    else
        return n1; 
} 

void SPI_Transmit(uint8_t data)			//function to transmit 8 bit digital pot wiper position via the SPI
{
	USIDR = 0b00010011;					//command byte  : write to all pots
	CSPORT &= ~(1<<CSPIN);				//Chip select pin set low : chip is selected
	USISR = _BV(USIOIF);
	while((USISR &_BV(USIOIF))==0)
	{
		USICR = (1<<USIWM0) | (1<<USICS1) | (1<<USICLK) | (1<<USITC);
	}
	USIDR = data;						//wiper position in USI data register
	USISR = _BV(USIOIF);
	while((USISR &_BV(USIOIF))==0)
	{
		USICR = (1<<USIWM0) | (1<<USICS1) | (1<<USICLK) | (1<<USITC);
	}
	CSPORT |= (1<<CSPIN);				//Chip select pin set high after 16 clock cycles: transmission complete
}

void blink1(void)		//toggles led to verify interactions
{
	LEDPORT ^= (1<<LEDPIN);
	_delay_ms(150);
	LEDPORT ^= (1<<LEDPIN);
	_delay_ms(150);
}

void fastblink1(void)		//toggles led to verify interactions
{
	LEDPORT ^= (1<<LEDPIN);
	_delay_ms(100);
	LEDPORT ^= (1<<LEDPIN);
	_delay_ms(100);
}

uint8_t doubletime(void)
{
	if (bit_is_set(DOUBLESFR,DOUBLEBV))		//if button pressed
	{
		_delay_us(DEBOUNCE_TIME);				//wait debounce time
		if (bit_is_set(DOUBLESFR,DOUBLEBV)){return(1);}	//if still pressed return 1
		else{return(0);}	//if not return 0
	}
	else{return(0);}
}

void Timerinit(void)
{
	TCNT0 = 0;				//timer0, fast PWM, OCRA as TOP, enable compare A interrupt, 1024 prescaler
	OCR0A = 100;
	TCCR0A |= (1<<WGM00) | (1<<WGM01);
	TIMSK0 |= (1<<OCIE0A);
	TCCR0B |= (1<<WGM02) | (1<<CS02) | (1<<CS00);
	
	ICR1 = 999;	//timer1, fast PWM, ICR1 as TOP, enable overflow interrupt and compare A interrupt, no prescaler
	TCNT1 = 0;
	
	OCR1A = 300;
	TCCR1A |= (1<<COM1A1);
	TIMSK1 |= (1<<OCIE1A);
	
	TCCR1A |= (1<<WGM11);
	TIMSK1 |= (1<<TOIE1);
	TCCR1B |= (1<<WGM12) | (1<<WGM13) | (1<<CS11);
}

void IOinit(void)
{
	LEDDDR |= (1<<LEDPIN);	//LED pins as output
	PWMDDR |= (1<<PWMPIN);	//PWM pin as output
	SPIDDR |= (1<<CLKPIN) | (1<<DATAPIN); //SPI pins as output
	CSDDR |= (1<<CSPIN);
	
	BUTTONPORT |= (1<<BUTTONPIN); //Connecting Pull-Up Resistors
	MODPORT |= (1<<WAVEPIN);
	DIVPORT |= (1<<DIVPIN);
	CSPORT |= (1<<CSPIN);	//Chip select pin high (not selected)
}

void ADCinit(void)
{
	ADCSRA |= (1<<ADEN) | (1<<ADIE) | (1<<ADPS2) | (1<<ADPS1) | (1<<ADPS0); //Enabling ADC, 16 prescaler, ADC interrupts enable
	ADCSRB |= (1<<ADLAR); //8bit conversion
}

ISR(ADC_vect)					//ADC interrupt
{
	switch(ADMUX)
	{
		case 0x00:
		timevalue = ADCH;		//Stocking 8-bit value
		ADMUX |= (1<<MUX0);		//changing to next ADC Channel
		break;
	
		case 0x01:
		divtogglevalue = ADCH;
		ADMUX &= ~(1<<MUX0);
		ADMUX |= (1<<MUX1);
		break;
		
		case 0x02:
		speedvalue = ADCH;
		ADMUX |= (1<<MUX0);
		break;
	
		case 0x03:
		depthvalue = ADCH;
		ADMUX |= (1<<MUX2);
		break;
		
		case 0x07:
		wavevalue = ADCH;
		ADMUX &= ~(1<<MUX0) & ~(1<<MUX1) & ~(1<<MUX2);
		break;
	}
	ADCSRA |= (1<<ADSC);	//Restarting conversion
}

ISR(TIM1_OVF_vect)
{
	msturns++;	//ms increment if timer1 overflow
	ledturns++;
}

ISR(TIM1_COMPA_vect)
{
	cli();		//updates mod pwm duty cycle
	OCR1A = pwm;
	sei();
}

ISR(TIM0_COMPA_vect)
{
	inc++;		//increment position in wavetable
	cli();
	OCR0A = speed;	//update mod speed
	sei();
}

int main(void)
{	
	_delay_ms(1000); //Waiting for PT2399 to start-up
	
	IOinit();
	Timerinit();
	ADCinit();
	
	uint16_t divtempo;		//The current tempo tapped (it will  be multiplied by the tempo div)
	uint16_t mstempo = eeprom_read_word((uint16_t*)2);		//tempo for toggling LED (not influenced by tempo div)
	//uint8_t delaymin = 51;
	uint16_t delaymax = eeprom_read_word((uint16_t*)100);	//maximum tempo if not in clean mode
	uint16_t offset;
	//int8_t pwmfine[] = {25,21,16,11,6,0,-7,-11,-15,-19,-23};	//pwm values for +-5ms offset
	//int8_t delta;
	unsigned long cleantimevalue;
	
	uint16_t nbtap = 0;		//number of times tapped during the current sequence
	uint8_t laststate = 0;	//last state of the button
	uint8_t tap = eeprom_read_byte((uint8_t*)1);		//tap controlled (1) or pot controlled (0)
	uint8_t tapping = 0;	//led follow tap (1) or follow tempo (0)
	
	uint8_t data;	//to store digital pot wiper position
	
	uint8_t previoustimevalue;	//to know if the time pot moved
	uint16_t previousdiv = 900;	//to know if the div toggle moved, set >255+50 so that div is checked at startup
	float divmult = 1;				//the div tempo multiplicand
	
	uint16_t previouswave = 900;	//to know if waveform toggle moved, set >255+50 so that waveform is checked at startup
	uint8_t wavetype = 0;			//this value selects one of the 6 waveforms
	
	uint8_t cleanmode = eeprom_read_byte((uint8_t*)0);	//read clean mode status from eeprom
	
	uint16_t block = 0; //is used for delaying the time and tap button read at startup, (the eeprom time save is not taken into account otherwise) 
	
	uint8_t speedpresetactive = 0;	//is the speed preset value used?
	uint8_t depthpresetactive = 0;	//is the depth preset value used?
	uint8_t timepresetactive = 0;	//is the depth preset value used?
	uint8_t presetspeed;	//for storing preset values
	uint32_t presetdepth;
	uint8_t previousspeed;	//for detecting if speed pot moved
	uint32_t previousdepth;	//for detecting if depth pot moved
	uint8_t previousdoubletime = doubletime(); //for detecting if double time pin changed state
	
	uint8_t calibrated = eeprom_read_byte((uint8_t *)200);	//reads if already calibrated
	float timecal;
	float useroffset[13]={0,0,0,0,0,0,0,0,0,0,0,0,0};	//array of manual calibration for every 100ms
	uint8_t j = 0;
	

//--------CLEAN MODE & RE-CALIBRATION 

		if (debounce()==1)
		{
			LEDPORT &= ~(1<<LEDPIN);
			blink1();			//if pressed long enough blink
			
			for (uint16_t c = 0; c < 2000; c++ )	//if button released during the 2s following the blinking
			{
				_delay_ms(1);
				if (debounce() == 0)
				{
					switch (cleanmode)
					{
						case 0x01:					//toggle the clean mode state and store it to eeprom
						cleanmode = 0;
						eeprom_update_byte((uint8_t*)0,0);
						break;
						
						default:
						cleanmode = 1;
						eeprom_update_byte((uint8_t*)0,1);
						break;
					}
					_delay_ms(150);
					fastblink1();
					_delay_ms(150);
					break;
				}
			}
			if (debounce()==1)
			{
				blink1();
				blink1();
				for (uint16_t c = 0; c < 2000; c++ )	//if button released during the 2s following the blinking
				{
					_delay_ms(1);
					if (debounce() == 0)
					{
						calibrated = 0;
						_delay_ms(150);
						fastblink1();
						fastblink1();
						_delay_ms(150);
						break;
					}
				}
			}
		}
		
		
	sei();			//activating interrupts
	
	ADCSRA |= (1<<ADSC); //Starting first AD conversion
	
	//-------------CALIBRATION
	
	if (calibrated != 13)
	{
		delaymax = 1291;
		j=0;
		calibrated = 3;
		pwm = 300;
		while(calibrated!=13)
		{
			timecal=timevalue;
			
			if(calibrated<=11){
				mstempo = (calibrated+1)*100;
				useroffset[calibrated] = ((timecal * (mstempo/3)) / 255) - (mstempo/6);
				//if (mstempo + useroffset[calibrated] > delaymax){useroffset[calibrated] = delaymax - findClosest(mstempo);} //no overflow in useroffset
				data = findClosest(mstempo + useroffset[calibrated]);
				SPI_Transmit(data);
				}
				
			else{
				SPI_Transmit(255);
				delaymax = 1491 - ((timecal*400)/255);
				mstempo = delaymax;
			}
			
			if (ledturns >= mstempo - 4)	//turns LED on every downbeat
			{
				ledturns = 0;
				LEDPORT |= (1<<LEDPIN);
			}
			
			if (ledturns >= 8){LEDPORT &= ~(1<<LEDPIN);}	//turns LED off 4ms after downbeat
			
			if (laststate == 1 && debounce()==0){laststate =0;}
				
			if (debounce()==1 && laststate == 0)
			{
				laststate = 1;
				calibrated++;
			}
		}
		for (uint8_t i= 96; i<=144; i+=4)	//stocks all useroffset to eeprom
		{
			eeprom_update_float((float *)i, useroffset[j]);
			j++;
		}
		eeprom_update_byte((uint8_t *)200, 13); //stocks calibrated status to eeprom
		eeprom_update_word((uint16_t*)100, delaymax); //stocks delaymax to eeprom
	}
	
	else
	{
		j=0;
		for(uint8_t i = 96; i<=144; i+=4) //retrieves useroffset from eeprom every power up after calibration
		{
			useroffset[j]=eeprom_read_float((float *)i);
			j++;
		}
	}
	
	if (cleanmode == 1){delaymax = 600;}	//if in clean mode the maximum delay is now 600ms
	
	if (tap != 1){SPI_Transmit(mstempo);}
	
	
    while (1) 
    {
		//---------PWM OUTPUT
		
		
		if (depthpresetactive == 1){offset = (300 - ((presetdepth * 300)/255));}	//updating mod pwm value

		if (depthpresetactive == 0 || abs(depthvalue - previousdepth) >= 13)
		{
			depthpresetactive = 0;
			offset = (300 - ((depthvalue * 300)/255));	//updating mod pwm value
		}
		
		/*if (tap == 1)
		{
			delta = divtempo - pgm_read_word_near(tempo + data);	//difference between tempo tapped and closest tempo in conversion chart
			offset += pwmfine[delta + 5];	//compensate with pwm if tap tempo is active
		}*/
		
		if (depthpresetactive == 1){pwm = (((100 + currentinc) * presetdepth)/255) + offset;}
			
		else{pwm = (((100 + currentinc) * depthvalue)/255) + offset;}
		
		
		
		
		//-----------MODULATION SPEED & WAVEFORMS
		
		if (speedpresetactive == 1){speed = 255 - presetspeed;}	//updating mod speed
			
		if (speedpresetactive == 0 || abs(speedvalue - previousspeed) >= 13)
		{
			speedpresetactive = 0;
			speed = 255 - speedvalue; //updating mod speed
		}
		
		if (speed < 3){speed = 3;}	//limiting speed, it bugs if lower than 3
	
		if (abs(previouswave-wavevalue) > 50)	//if wave toggle moves, update waveform
		{
			if (debounce() == 0)	//if tap button not pressed use first 3 waveforms
			{
				if (wavevalue <= 50){wavetype = 0;}
			
				if (wavevalue > 50 && wavevalue < 230 ){wavetype = 1;}
			
				if (wavevalue >= 230){wavetype = 2;}
			}
		
			if (debounce() == 1)		//if tap button pressed while moving waveform toggle use alternate waveforms
			{
				if (wavevalue <= 50){wavetype = 3;}
			
				if (wavevalue > 50 && wavevalue < 230){wavetype = 4;}
			
				if (wavevalue >=230){wavetype = 5;}
					
				laststate = 1;		//press doesn't count as tap for tap tempo
				nbtap = 0;
				tapping = 0;
				msturns = 0;
			}
		
			previouswave = wavevalue;	//update previouswave for next toggle move
		}
	
		//update mod waveform value
		if (wavetype == 0){currentinc = (int)((sin(((2 * PI) / 255) * inc)*200) + 200);}	//Sine
	
		if (wavetype == 1)	//Square
		{
			if (inc <=127){currentinc = 0;}
			else{currentinc = 400;}
		}
	
		if (wavetype == 2)	//Triangle
		{
			if (inc <= 127){currentinc = round((400 / 127) * inc);}
			else{currentinc = round((400 / 127) * (127 - (inc - 128)));}
		}
		
		if (wavetype == 3){currentinc = round((400 / 255)* inc);}	//Sawtooth
		
		if (wavetype == 4){currentinc = round((400 / 255) * (255-inc));}	//Reverse Sawtooth
		
		if (wavetype == 5 && (inc%50) == 0){currentinc = rand() / (RAND_MAX / 401);}	//random
		
		
		
		//---------DOUBLE TIME
		
		if (doubletime() != previousdoubletime)
		{
			if (doubletime()==1){divmult /= 2;}
			else{divmult *= 2;}
				if (tap == 1)
				{
					divtempo = round(mstempo * divmult);
					if (divtempo > delaymax)
					{
						divtempo = delaymax;
						mstempo = delaymax / divmult;
					}
					data = findClosest(divtempo + useroffset[(int)((divtempo+50)/100)]);
					SPI_Transmit(data);
				}
			previousdoubletime = doubletime();
		}
		
		
		
		
		//----------DELAY TIME POT
		
		if(block < 200)	//blocks the tap button input, div update and the delay time input for 200 loops. This helps stabilizing the save tempo and preset recall.
		{
			previoustimevalue = timevalue;
			block++;
		}
				
		if ((tap == 1 && abs(previoustimevalue-timevalue) >= 15) || (timepresetactive == 1 && tap == 0 && abs(previoustimevalue-timevalue) >= 15) || (timepresetactive == 0 && tap == 0 && abs(previoustimevalue-timevalue) >= 1))//if pot move of more than 5%, changing to pot control
		{
			if (cleanmode == 1)		//if clean mode active time pot course divided per 2
			{
				cleantimevalue = (timevalue*127)/255;
				SPI_Transmit(cleantimevalue);
				mstempo = cleantimevalue;	//mstempo used to stock directly digi pot wiper position (for presets)
			}
			else
			{
				SPI_Transmit(timevalue);
				mstempo = timevalue;	//mstempo used to stock directly digi pot wiper position (for presets)
			}
			
			previoustimevalue = timevalue;
			timepresetactive = 0;
			tap = 0;
			TCNT1 = 0;
		}
		
		if (tap == 0 && TCNT1 >=800)
		{
			eeprom_update_byte((uint8_t*)1, 0);	//write tap = 0 to eeprom when the pot stops moving
			eeprom_update_word((uint16_t*)2, mstempo);	//Using ms tempo to stock digi pot wiper position
		}
		
		
		
		//-------------TIME DIVISION
		
		if (abs(previousdiv - divtogglevalue) > 50 && block >= 200)		//if first time or if div toggle changed position : update div
		{
			if (debounce() == 0)	//if tap button not pressed while changing 3 first div
			{
				if (divtogglevalue <= 50){divmult = 1;}	//fourth
			
				if (divtogglevalue > 50 && divtogglevalue < 230){divmult = 0.75;}	//dotted eighth
				
				if (divtogglevalue >= 230){divmult = 0.5;}	//eighth
			}
			
			if (debounce() == 1)	//if tap button pressed while changing 3 last div
			{
				if (divtogglevalue <= 50){divmult = 0.333333;}	//triplet
				
				if (divtogglevalue > 50 && divtogglevalue < 230){divmult = 0.25;}	//sixteenth
				
				if (divtogglevalue >= 230){	divmult = 0.1666666;}	//sextuplet
				
				nbtap = 0;			//don't count press as tap
				tapping = 0;
				msturns = 0;
				laststate = 1;
			}
			
			if (doubletime()==1){divmult /= 2;}
			
			if (tap == 1)	//if in tap control, update digital pot value
			{
				divtempo = round(mstempo * divmult);
				if (divtempo > delaymax)
				{
					divtempo = delaymax;
					mstempo = delaymax / divmult;
				}
				data = findClosest(divtempo + useroffset[(int)((divtempo+50)/100)]);
				SPI_Transmit(data);
			}
			
			ledturns = 0;
			previousdiv = divtogglevalue;	//reseting previousdiv to detect next move
		}
		
		
		
		
		
		//---------------TAP TEMPO
		
		if (debounce()==1 && laststate==0 && nbtap==0 && block >= 200) //first tap
		{
			TCNT1 = 0;			//starts counting
			msturns=0;
			nbtap++;
			laststate = 1;
			tapping = 1;
		}
		
		if (nbtap > 1 && msturns > (3*mstempo) && debounce()==0 && laststate==0) //if too long between taps  : resets
		{
			msturns = 0;
			nbtap = 0;
			tapping = 0;
			eeprom_update_word((uint16_t*)2, mstempo);
			eeprom_update_byte((uint8_t*)1, 1);
		}
		
		if (nbtap == 1 && msturns > ((delaymax/divmult) + 800) && debounce()==0 && laststate==0) //if tapped only once, reset once the max tempo for the div + 800ms passed
		{
			msturns = 0;
			nbtap = 0;
			tapping = 0;
			eeprom_update_word((uint16_t*)2, mstempo);
			eeprom_update_byte((uint8_t*)1, 1);
		}
		
		if (debounce()==0 && laststate ==1)	//release tap button
		{
			laststate = 0;
			LEDPORT &= ~(1<<LEDPIN);
		}
		
		if (debounce()==1 && laststate==0 && nbtap!=0) //not first tap
		{
			if (TCNT1 >= 500){msturns++;}	//round up value if timer counter more than 500µs
			
			if (nbtap == 1)		//if second tap, tempo = time elapsed between the 2 button press
			{
				divtempo = msturns * divmult;
				mstempo = msturns;
			}
			
			else		//if not second tap, average every tap
			{
				divtempo = round((divtempo + (msturns*divmult)) / 2);
				mstempo = round((mstempo + msturns)/2);
			}
			
			if (divtempo > delaymax)
			{
				divtempo = delaymax;
				mstempo = delaymax / divmult;
			}

			data = findClosest(divtempo + useroffset[(int)((divtempo+50)/100)]);			//wiper position returned by position in array
			SPI_Transmit(data);		//sending wiper position to digital pot
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
